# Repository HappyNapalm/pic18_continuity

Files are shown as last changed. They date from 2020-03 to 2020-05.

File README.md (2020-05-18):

# pic18_continuity
Repo for testing continuity

## TODO
* Hammer out the firmware.
* Set timer 3 up as the IO test timer. Make it 8 bits.
* Make footprint for push button.

##License
* Free for non commerical use.
* Remakes and spin offs must give credit to this project.

~Assemble boards to verify designs~

~Verify RJ45~

~Order Alpha Run~

~Get dimensions for DB9 connectors~

~Do battery footprint~

~Learn how to submit multiple boards in one design for vendor~

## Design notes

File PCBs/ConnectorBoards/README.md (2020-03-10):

This dir is to contain the modular boards that the central board can connect to.

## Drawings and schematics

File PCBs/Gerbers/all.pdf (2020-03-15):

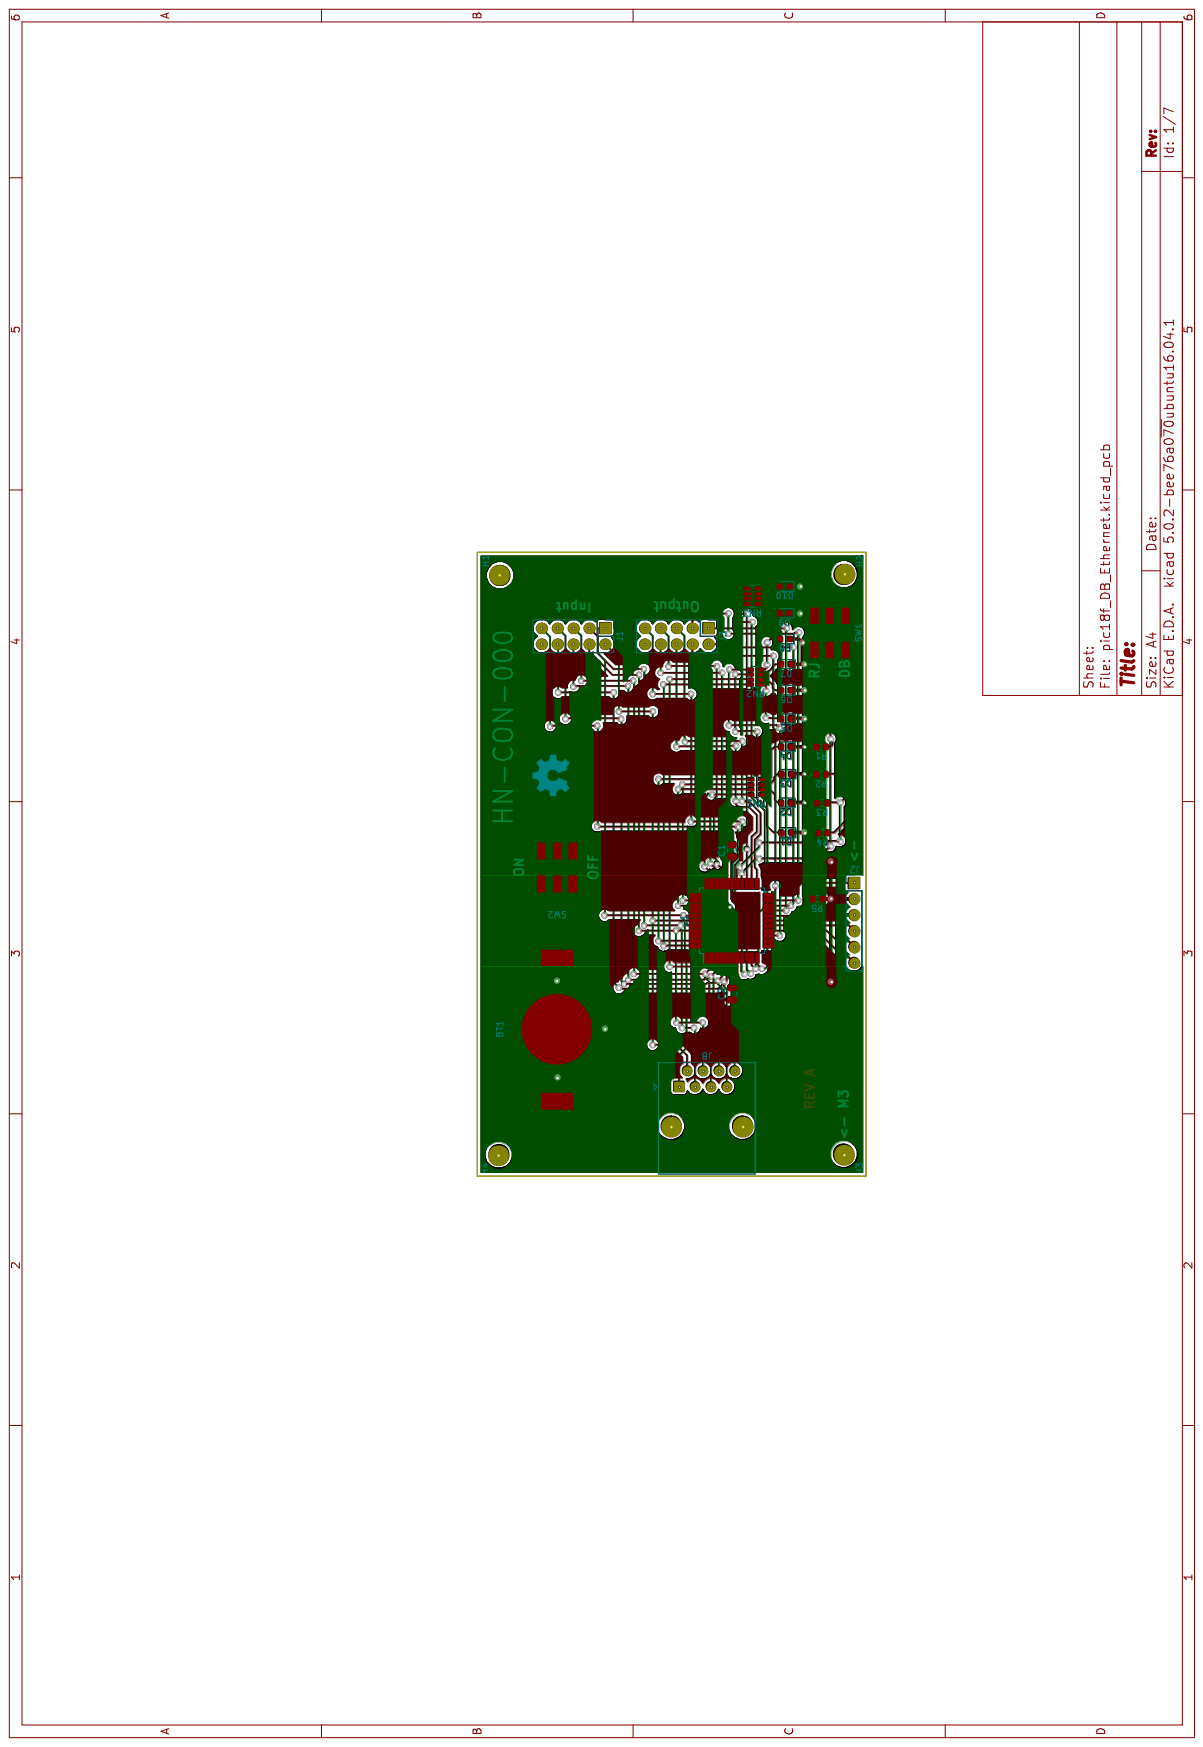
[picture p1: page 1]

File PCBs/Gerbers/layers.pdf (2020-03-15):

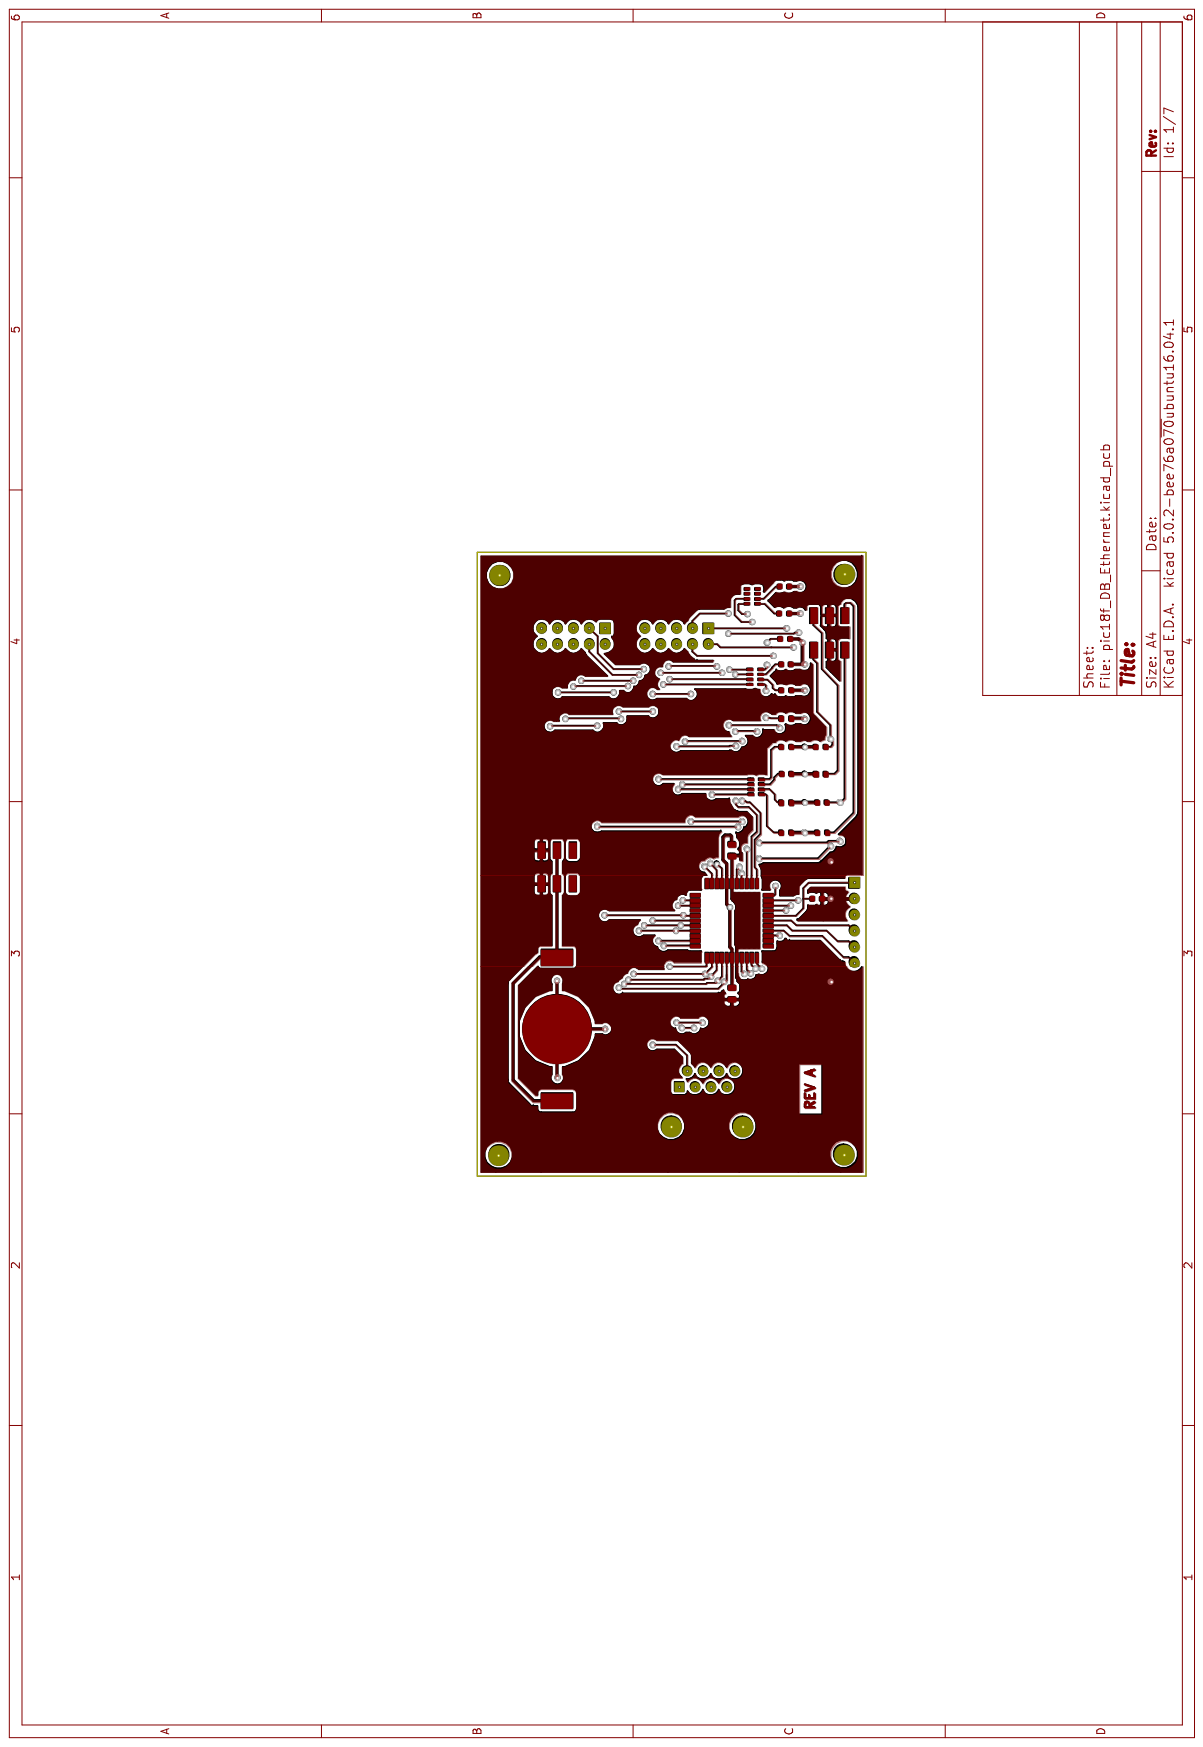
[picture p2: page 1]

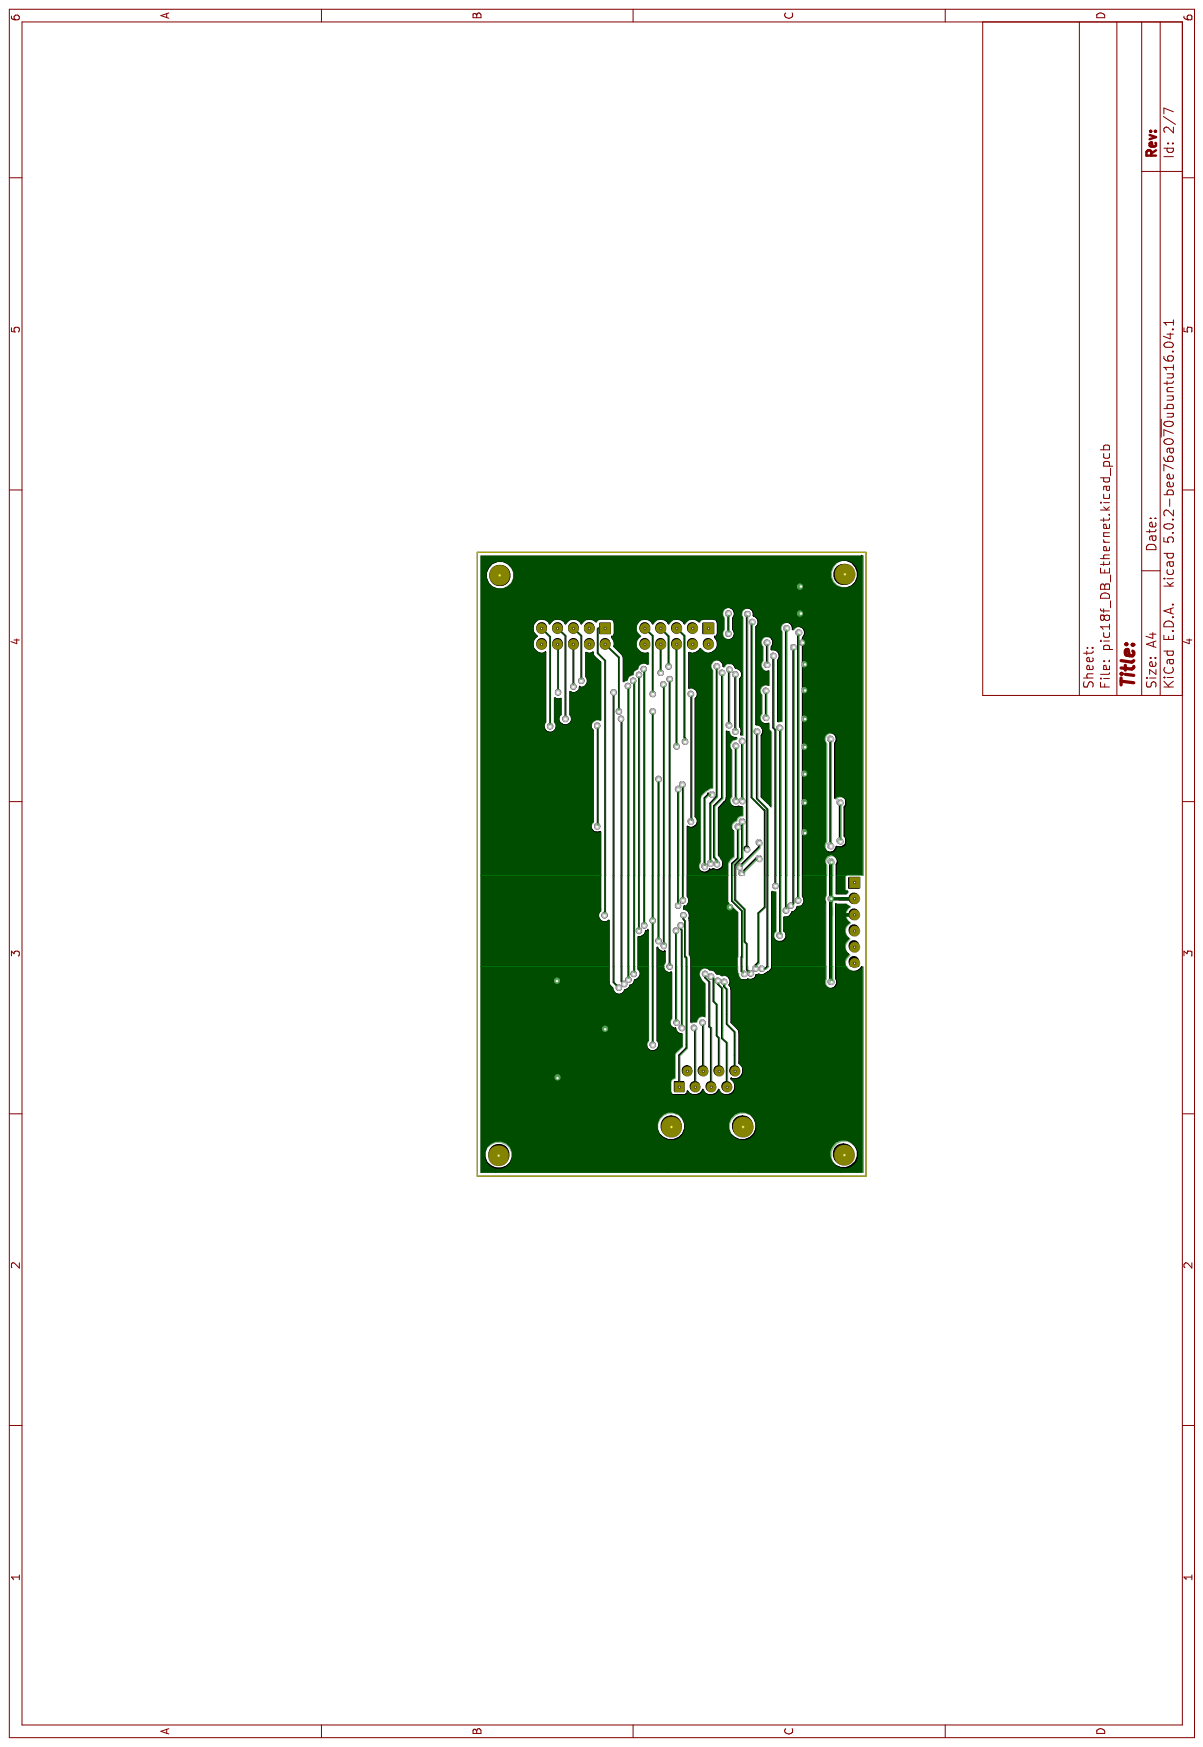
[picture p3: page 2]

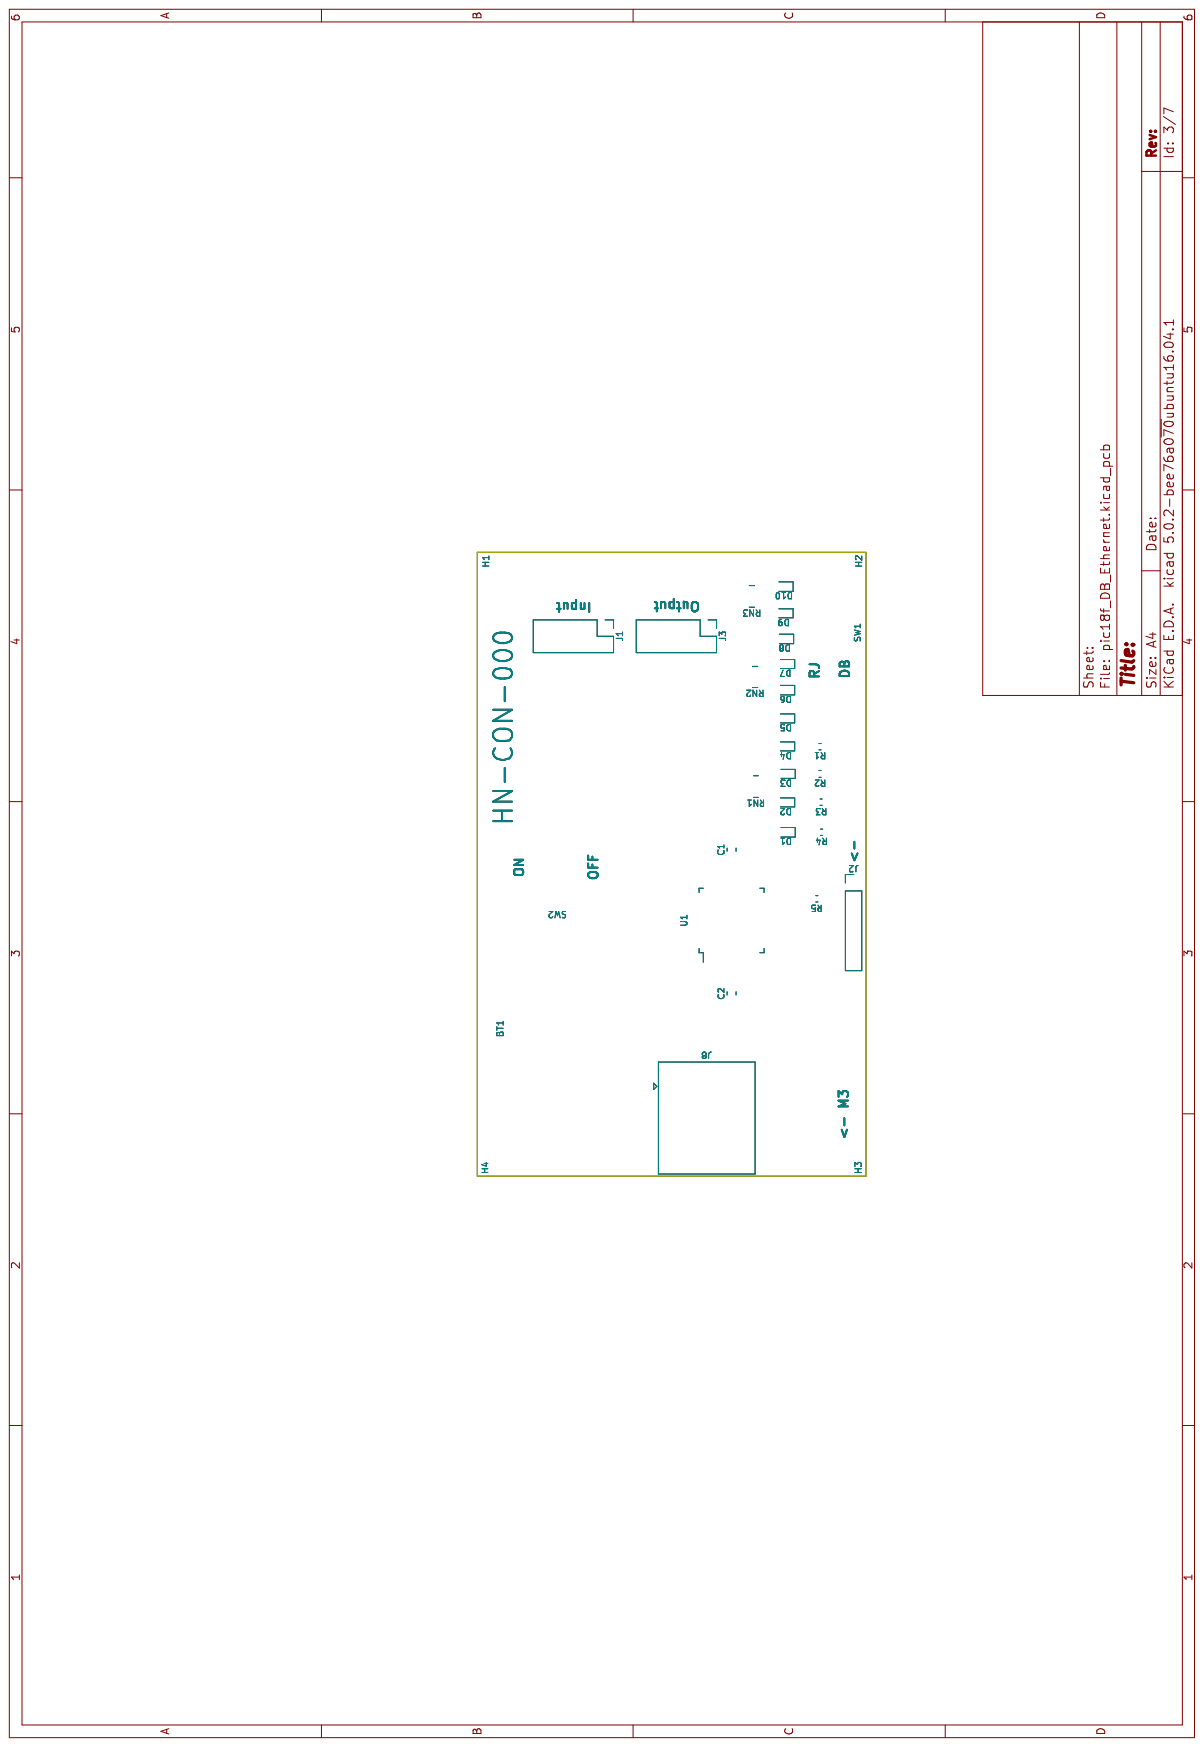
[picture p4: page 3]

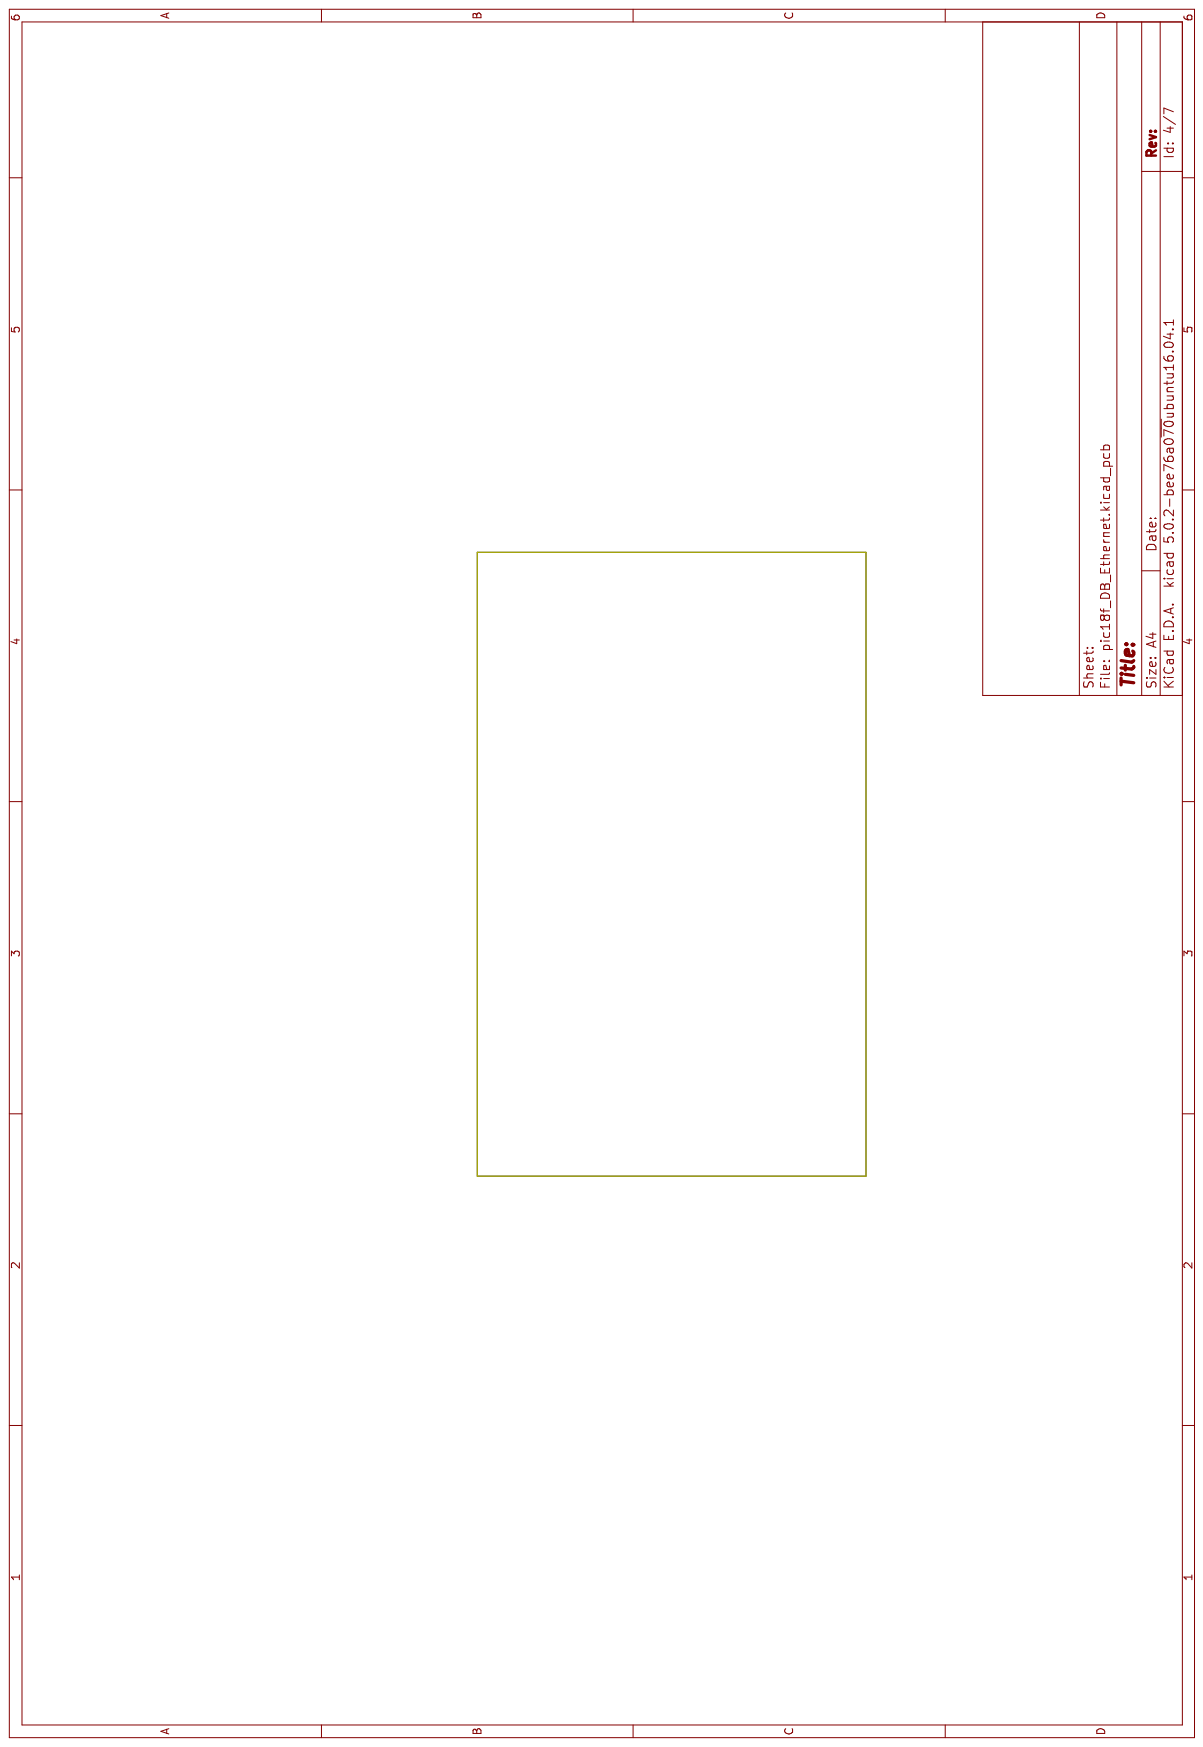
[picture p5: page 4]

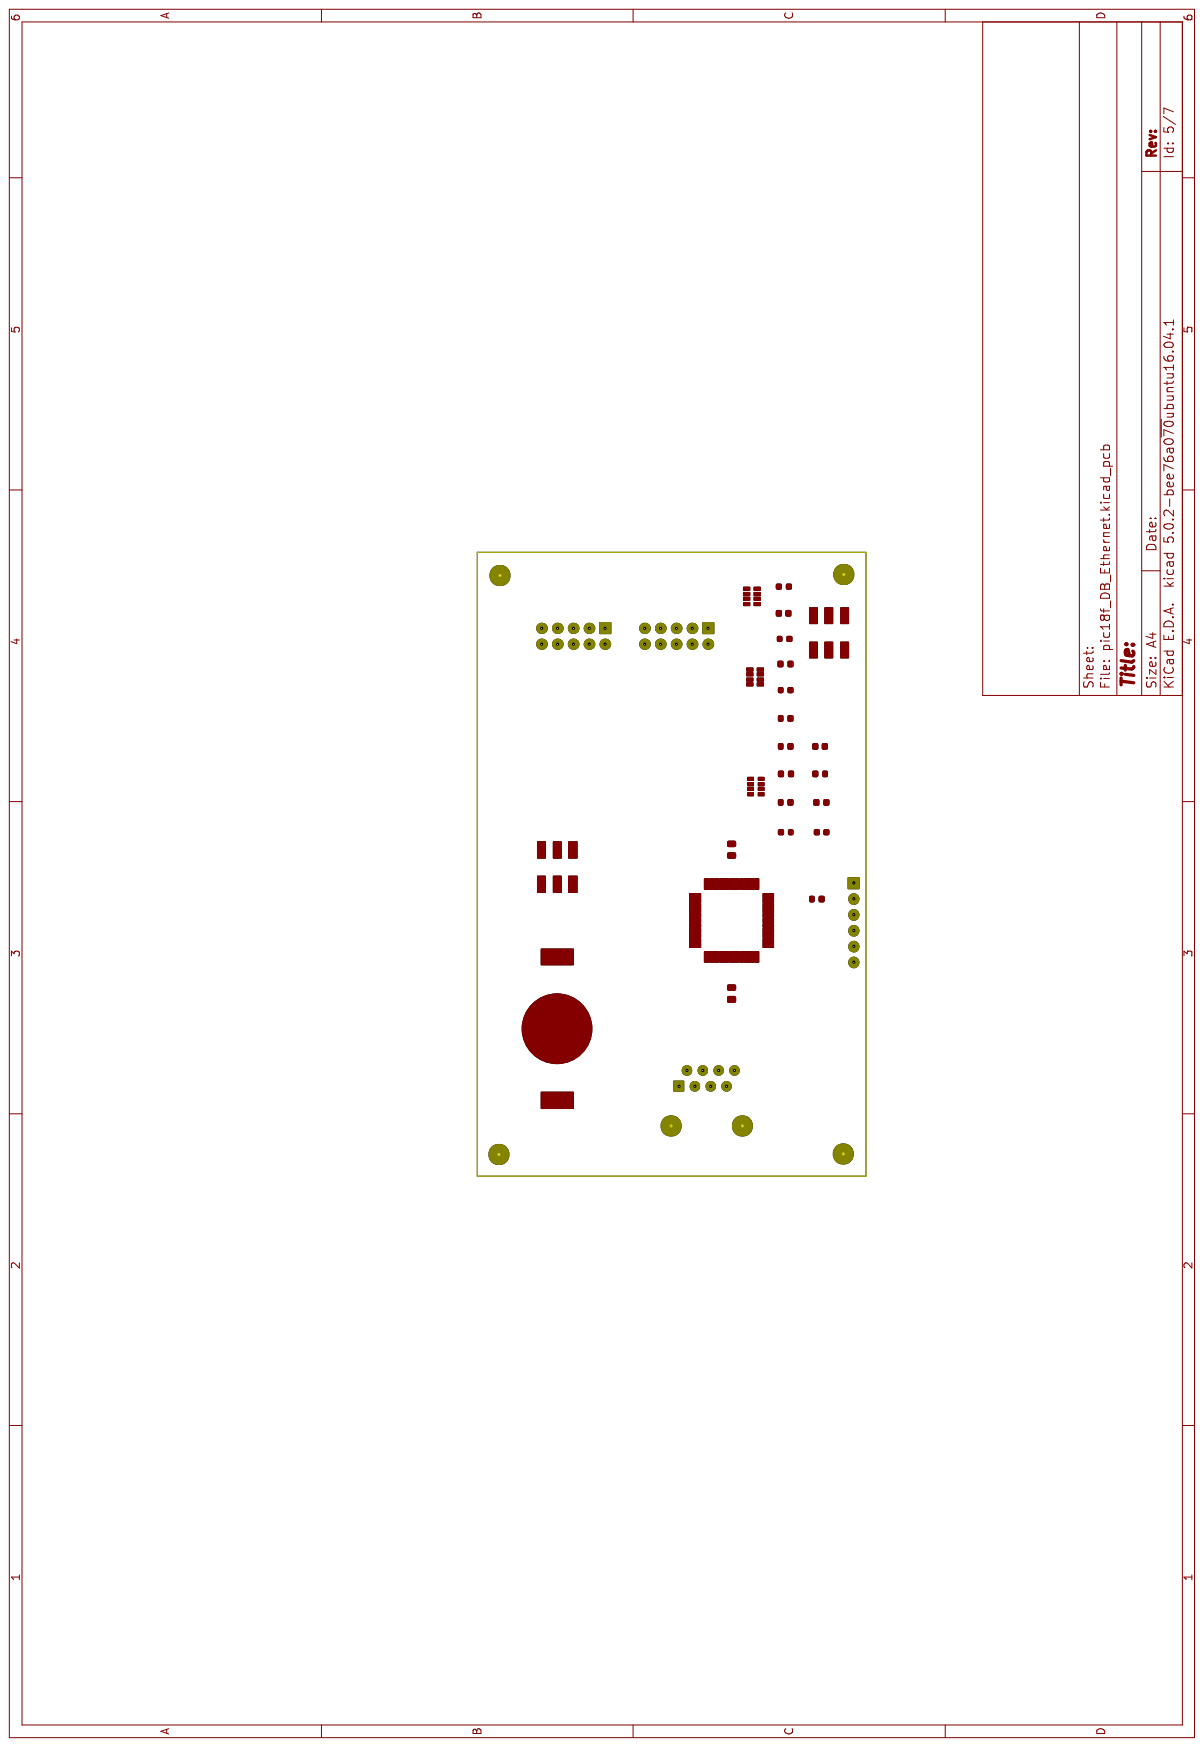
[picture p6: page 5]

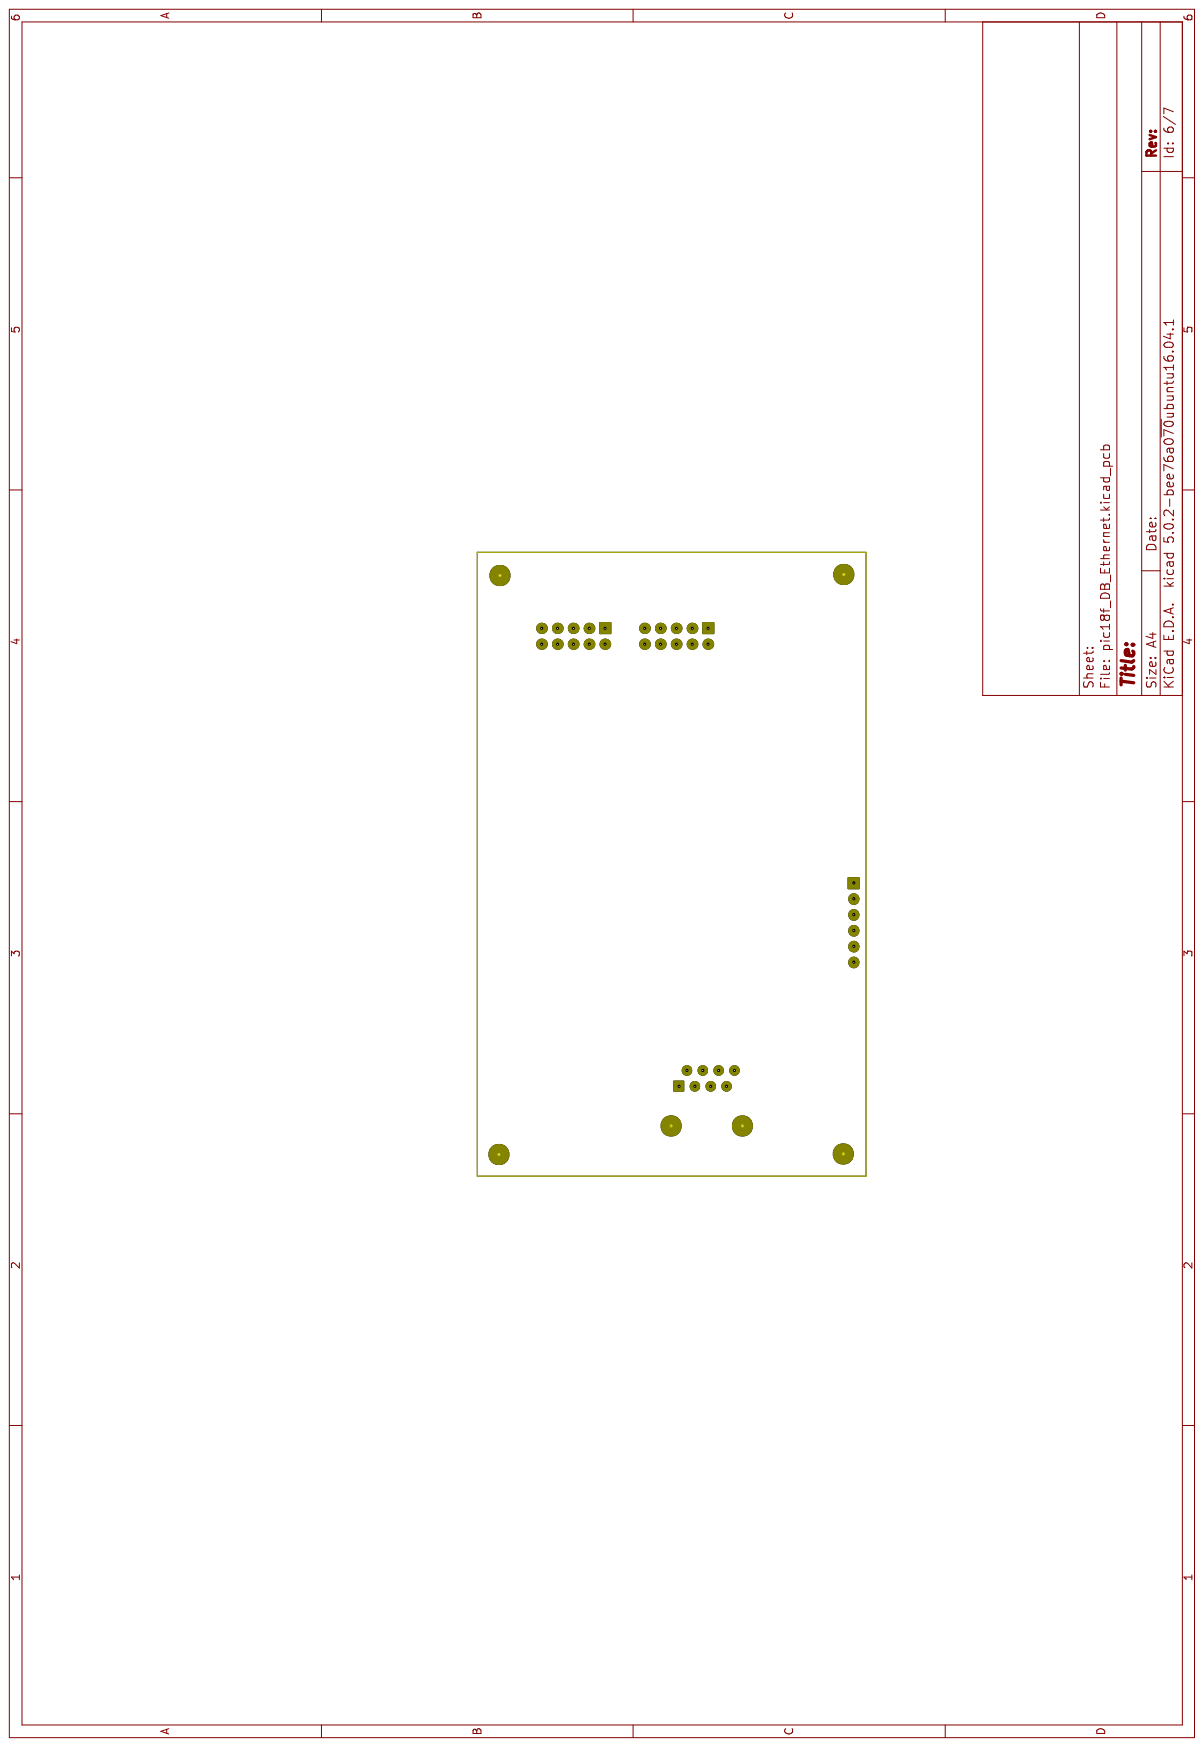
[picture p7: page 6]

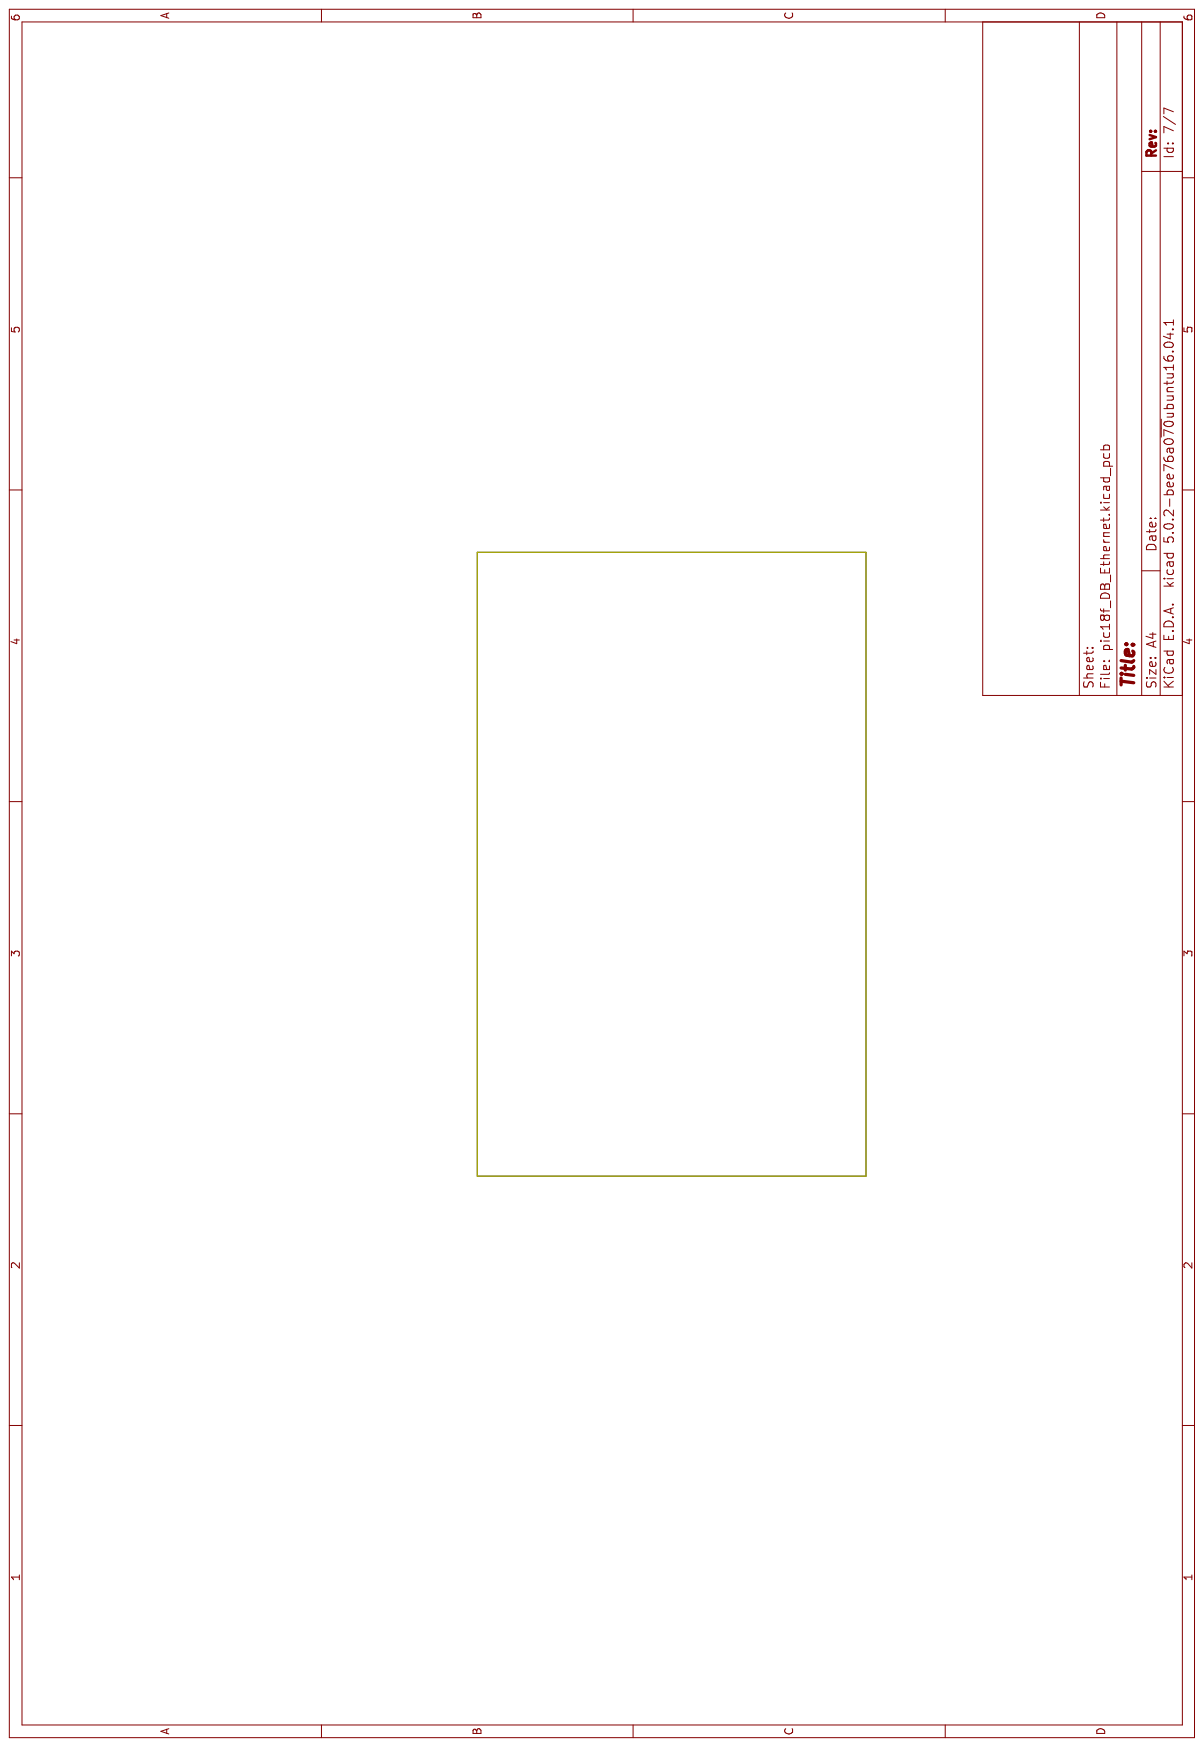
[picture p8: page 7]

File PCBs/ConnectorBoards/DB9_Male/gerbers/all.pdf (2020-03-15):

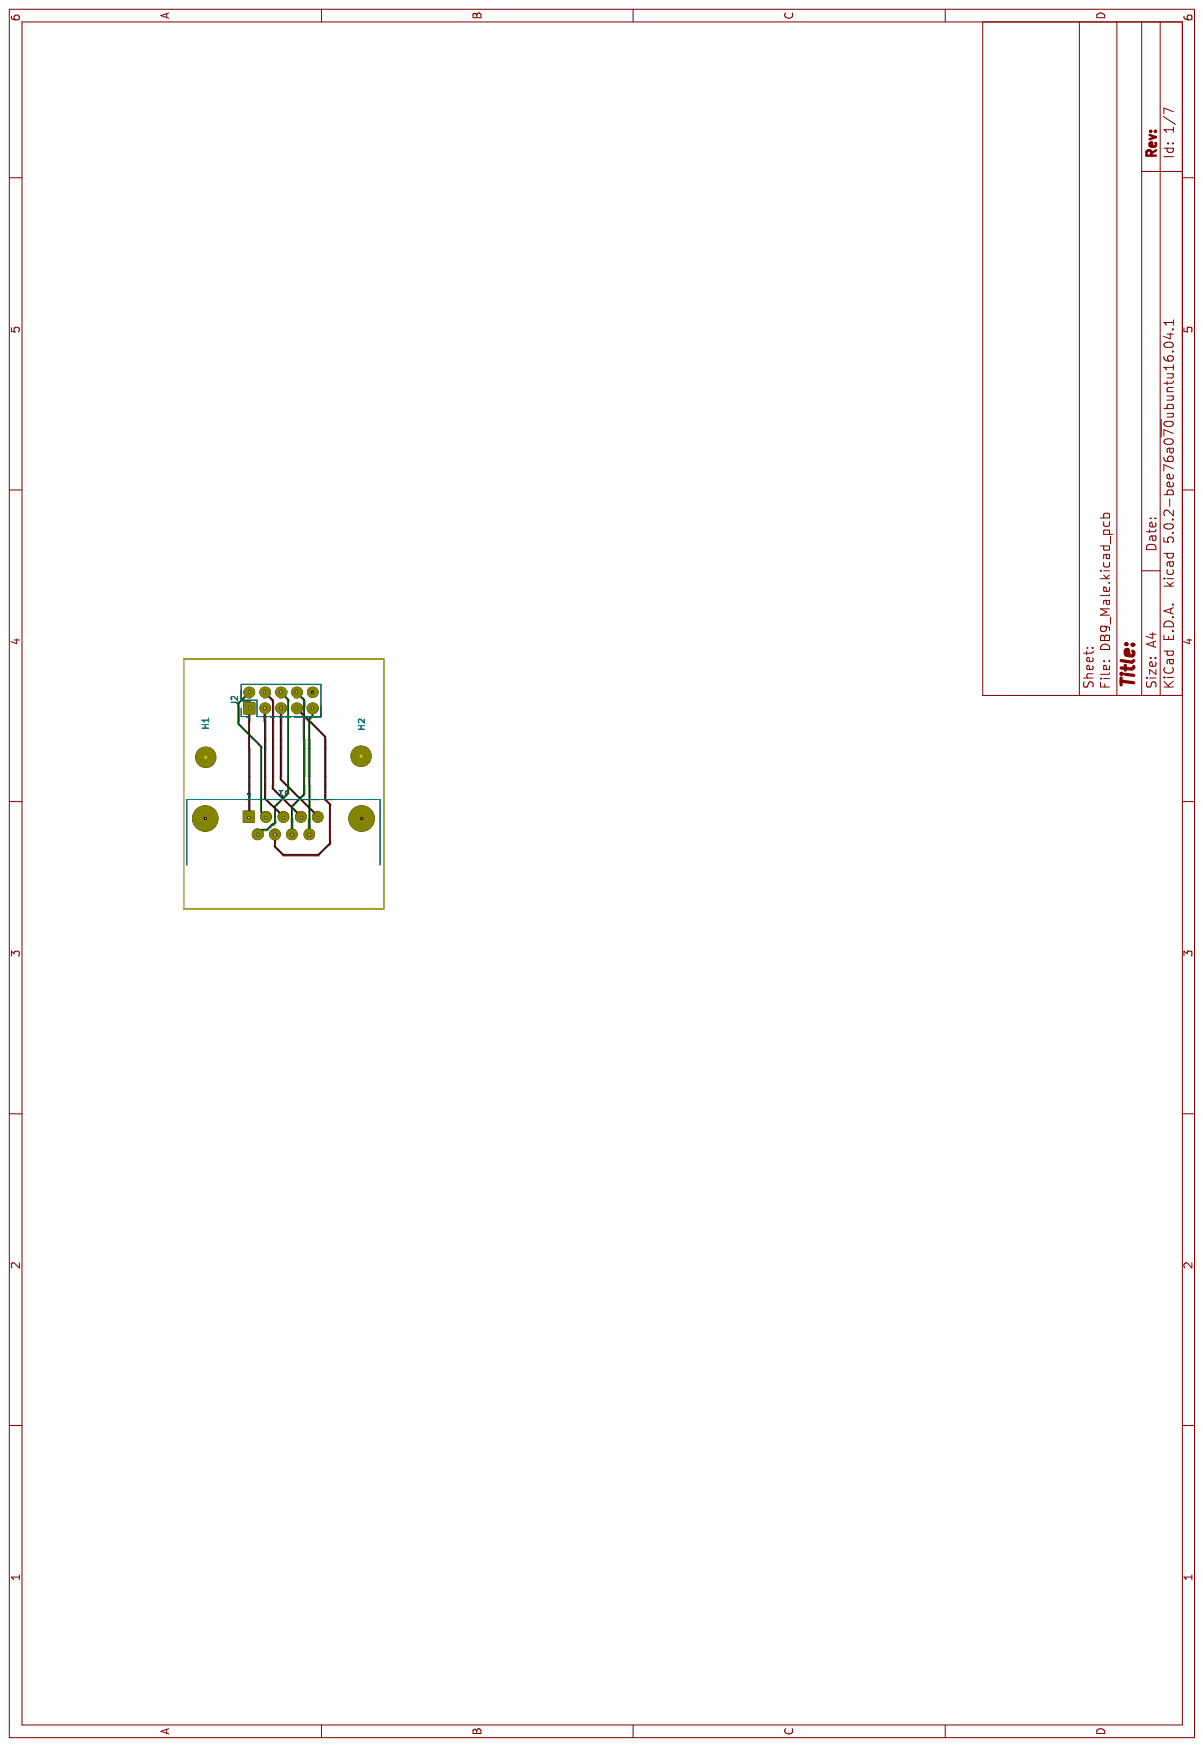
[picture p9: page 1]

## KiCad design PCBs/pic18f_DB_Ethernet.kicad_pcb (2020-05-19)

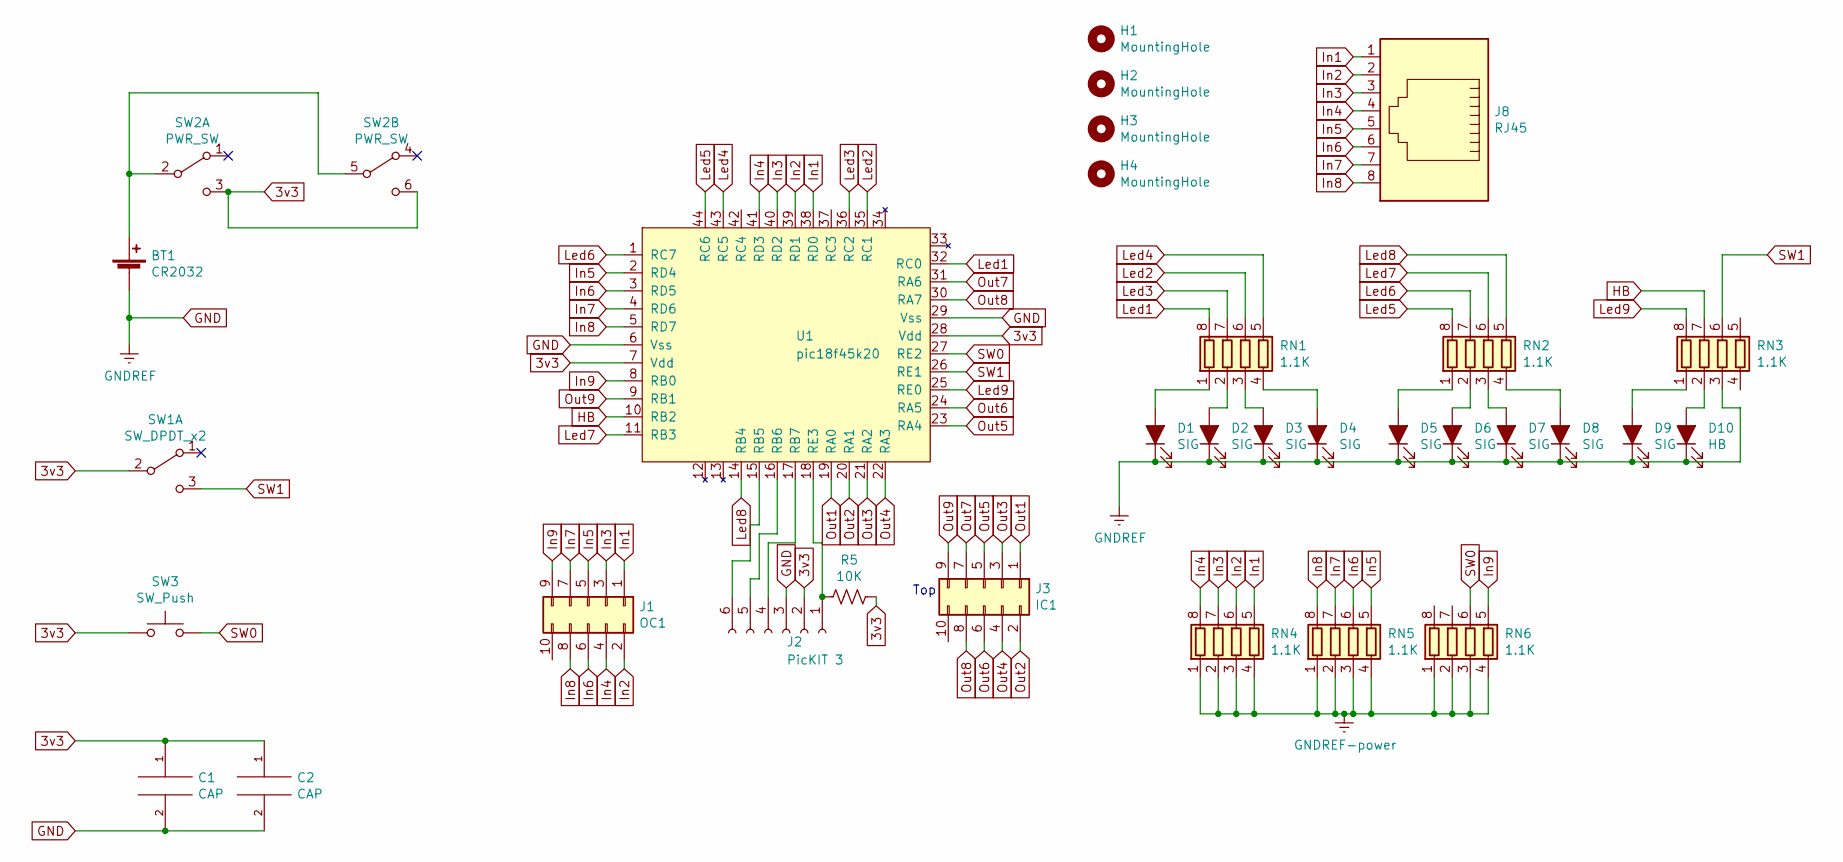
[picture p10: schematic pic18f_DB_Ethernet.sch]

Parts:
BT1: CR2032; BAT-HLD-001
C1, C2: CAP; C_0805_2012Metric
D1, D2, D3, D4, D5, D6, D7, D8, D9: SIG; LED_0603_1608Metric
D10: HB; LED_0603_1608Metric
H1, H2, H3, H4: MountingHole; MountingHole_3.2mm_M3
J1: OC1; PinHeader_2x05_P2.54mm_Vertical
J2: PicKIT 3; PinHeader_1x06_P2.54mm_Vertical
J3: IC1; PinHeader_2x05_P2.54mm_Vertical
J8: RJ45; RJ45_Amphenol_54602-x08_Horizontal
R5: 10K; R_0603_1608Metric
RN1, RN2, RN3, RN4, RN5, RN6: 1.1K; R_Array_Concave_4x0603
SW1: SW_DPDT_x2; JS202011SCQN
SW2: PWR_SW; JS202011SCQN
SW3: SW_Push; SPST_Button_FSM2JRT
U1: pic18f45k20; LQFP-44_10x10mm_P0.8mm

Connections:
3v3: C1.1, C2.1, J2.2, R5.1, SW1.2 (B), SW2.3 (C), SW2.6 (C), SW3.1, U1.7 (Vdd), U1.28 (Vdd)
HB: RN3.7 (R2.2), U1.10 (RB2)
In1: J1.1, J8.1, RN4.5 (R4.2), U1.38 (RD0)
In2: J1.2, J8.2, RN4.6 (R3.2), U1.39 (RD1)
In3: J1.3, J8.3, RN4.7 (R2.2), U1.40 (RD2)
In4: J1.4, J8.4, RN4.8 (R1.2), U1.41 (RD3)
In5: J1.5, J8.5, RN5.5 (R4.2), U1.2 (RD4)
In6: J1.6, J8.6, RN5.6 (R3.2), U1.3 (RD5)
In7: J1.7, J8.7, RN5.7 (R2.2), U1.4 (RD6)
In8: J1.8, J8.8, RN5.8 (R1.2), U1.5 (RD7)
In9: J1.9, RN6.5 (R4.2), U1.8 (RB0)
Led1: RN1.8 (R1.2), U1.32 (RC0)
Led2: RN1.6 (R3.2), U1.35 (RC1)
Led3: RN1.7 (R2.2), U1.36 (RC2)
Led4: RN1.5 (R4.2), U1.43 (RC5)
Led5: RN2.8 (R1.2), U1.44 (RC6)
Led6: RN2.7 (R2.2), U1.1 (RC7)
Led7: RN2.6 (R3.2), U1.11 (RB3)
Led8: RN2.5 (R4.2), U1.14 (RB4)
Led9: RN3.8 (R1.2), U1.25 (RE0)
unnamed: BT1.1 (+), SW2.2 (B), SW2.5 (B)
unnamed: D1.2 (A), RN1.1 (R1.1)
unnamed: D2.2 (A), RN1.2 (R2.1)
unnamed: D3.2 (A), RN1.3 (R3.1)
unnamed: D4.2 (A), RN1.4 (R4.1)
unnamed: D5.2 (A), RN2.1 (R1.1)
unnamed: D6.2 (A), RN2.2 (R2.1)
unnamed: D7.2 (A), RN2.3 (R3.1)
unnamed: D8.2 (A), RN2.4 (R4.1)
unnamed: D9.2 (A), RN3.1 (R1.1)
unnamed: D10.2 (A), RN3.2 (R2.1)
unnamed: J2.1, R5.2, U1.18 (RE3)
unnamed: J2.4, U1.17 (RB7)
unnamed: J2.5, U1.16 (RB6)
unnamed: J2.6, U1.15 (RB5)
Out1: J3.1, U1.19 (RA0)
Out2: J3.2, U1.20 (RA1)
Out3: J3.3, U1.21 (RA2)
Out4: J3.4, U1.22 (RA3)
Out5: J3.5, U1.23 (RA4)
Out6: J3.6, U1.24 (RA5)
Out7: J3.7, U1.31 (RA6)
Out8: J3.8, U1.30 (RA7)
Out9: J3.9, U1.9 (RB1)
SW0: RN6.6 (R3.2), SW3.2, U1.27 (RE2)
SW1: RN3.6 (R3.2), SW1.3 (C), U1.26 (RE1)

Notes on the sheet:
Top

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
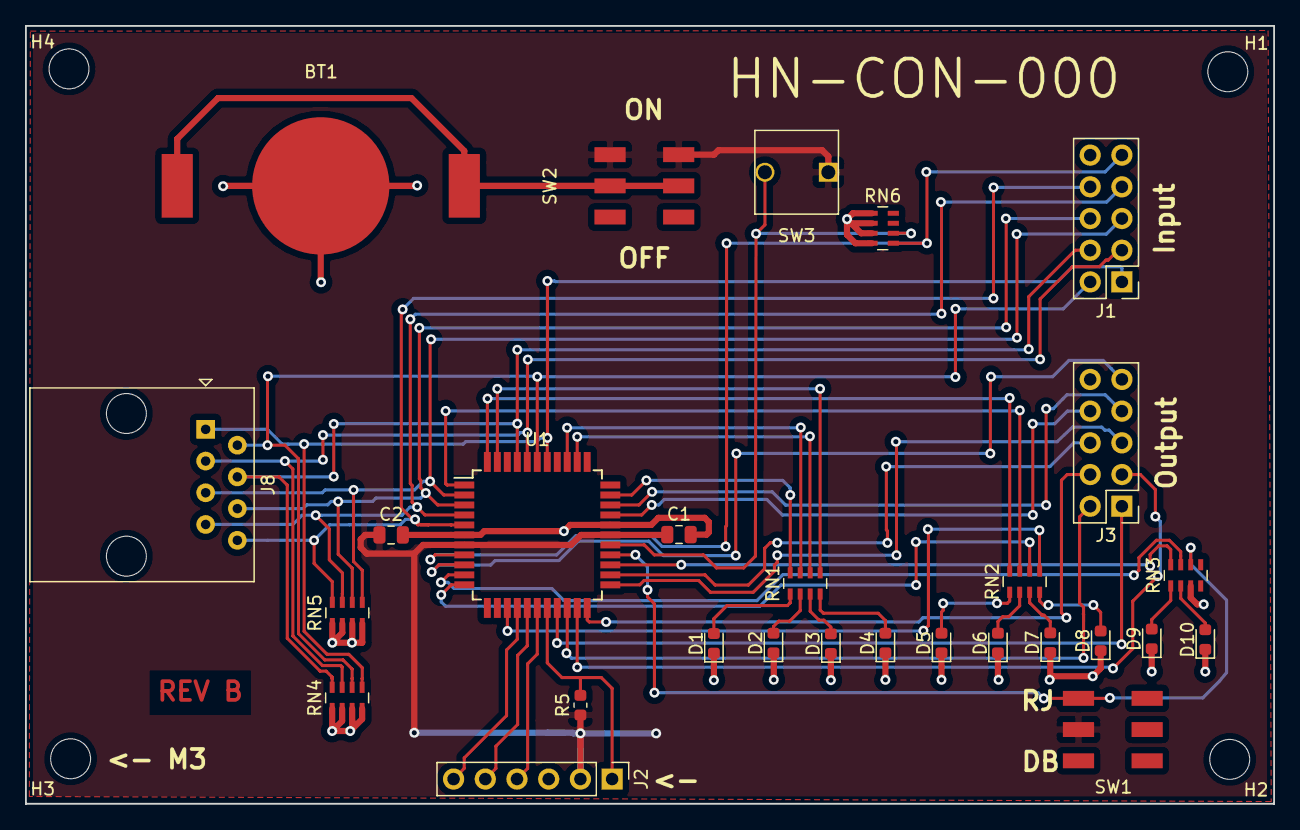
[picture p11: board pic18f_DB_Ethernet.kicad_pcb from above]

Board: 2 copper layers, 100.0 x 62.3 mm, 32 parts (0 on the bottom side), 47 nets.

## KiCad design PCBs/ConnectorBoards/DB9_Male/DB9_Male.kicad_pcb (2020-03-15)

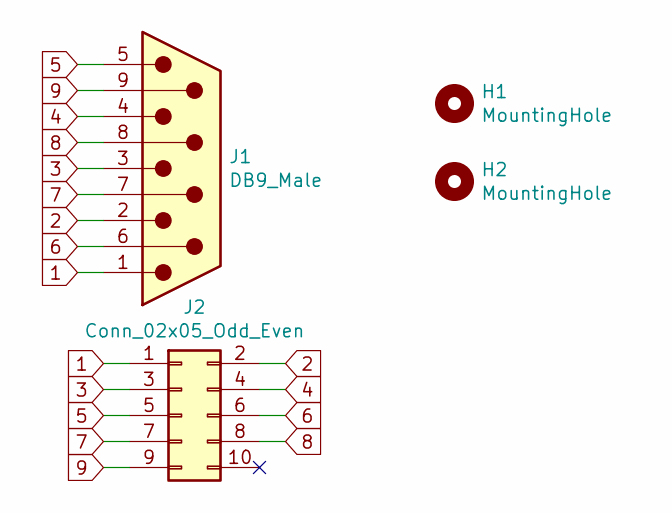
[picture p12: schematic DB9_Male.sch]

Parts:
H1, H2: MountingHole; MountingHole_3.2mm_M3
J1: DB9_Male; DSUB-9_Male_Horizontal_P2.77x2.84mm_EdgePinOffset4.94mm_Hou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
J2: Conn_02x05_Odd_Even; PinHeader_2x05_P2.54mm_Vertical

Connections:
1: J1.1, J2.1
2: J1.2, J2.2
3: J1.3, J2.3
4: J1.4, J2.4
5: J1.5, J2.5
6: J1.6, J2.6
7: J1.7, J2.7
8: J1.8, J2.8
9: J1.9, J2.9

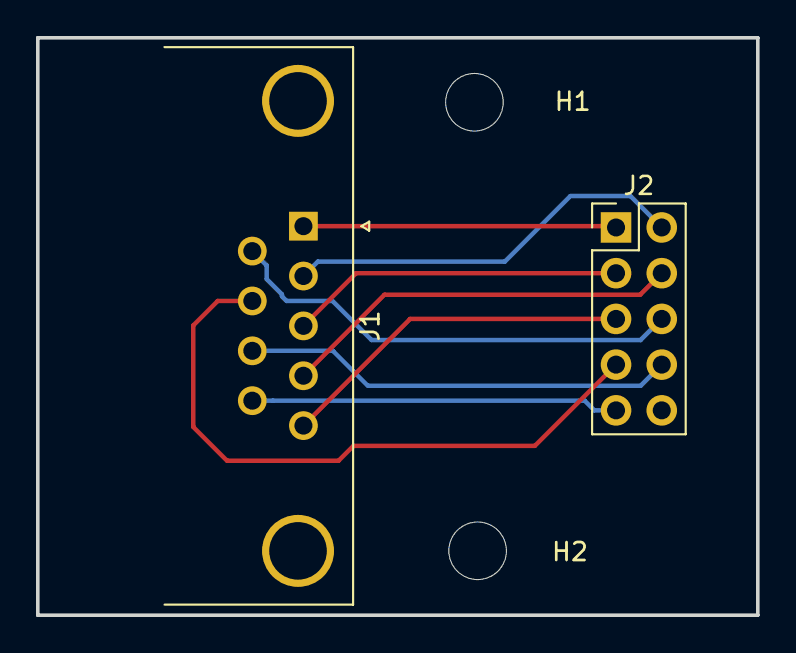
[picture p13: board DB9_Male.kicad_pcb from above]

Board: 2 copper layers, 40.0 x 32.1 mm, 4 parts (0 on the bottom side), 9 nets.

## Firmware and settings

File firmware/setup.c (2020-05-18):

#include <stdio.h>
//#include <stdlib.h>
#include <xc.h>
#include <htc.h>
#include "setup.h"
#include "leds.h"

//@About set GPIO table item to boolean
void set_IO (struct gstGPIO *IO, unsigned char item,unsigned char bValue)
{
    volatile unsigned char *ucLocal;
    ucLocal = IO[item].port;
    if (bValue)
    {
        *ucLocal |= (1 << IO[item].pin);
    }
    else
    {
        *ucLocal &= ~(1 << IO[item].pin);
    }
}

//@About get the state of an item from a GPIO table
unsigned char get_IO (struct gstGPIO *IO, unsigned char item)
{
    return (unsigned char)((*IO[item].port >> IO[item].pin) & 0x01);
}

struct gstGPIO astInputs[] = {
    {&PORTD, 0},
    {&PORTD, 1},
    {&PORTD, 2},
    {&PORTD, 3},
    {&PORTD, 4},
    {&PORTD, 5},
    {&PORTD, 6},
    {&PORTD, 7},
    {&PORTB, 0},
};

struct gstGPIO astOutputs[] = {
    {&LATA, 0},
    {&LATA, 1},
    {&LATA, 2},
    {&LATA, 3},
    {&LATA, 4},
    {&LATA, 5},
    {&LATA, 6},
    {&LATA, 7},
    {&LATB, 1},
};

void IO_setup (void)
{
  TRISA = 0x00;           //Outputs
  TRISC = 0x00;           //LEDS
  TRISBbits.RB0 = 1;      //In9
  TRISBbits.RB1 = 0;      //Out9
  TRISBbits.RB2 = 0;      //HB
  TRISBbits.RB3 = 0;      //LED7
  TRISBbits.RB4 = 0;      //LED8
  TRISD = 0xFF;           //Inputs
  TRISEbits.RE0 = 0;      //LED9
  TRISEbits.RE1 = 1;      //Switch 1A
  TRISEbits.RE2 = 1;      //Switch 1B
}


void Timer_and_Interrupt_setup (void)
{
    //Let this timer run as a free running timer
    
    //16 bits. 1:64 prescaler. Internal. 1 tick is 8us
    T0CON = 0b10010101;
    //INTCONbits.TMR0IE = 1;
    
    //8Mhz timer. Internal
    OSCCON = 0b01100111;
    
    
    T3CON = 0b00000101;
}

void clr_Timer (void)
{
    TMR0H = 0;
    TMR0L = 0;
}

void clr_Timer3 (void)
{
    TMR3H = 0;
    TMR3L = 0;
}

void __interrupt() ISR()
{
    if(TMR0IF)
    {
        TMR0IF = 0;
        clr_Timer();
        HB = !HB;
        gbTick++;
    }
    if(TMR3IF)
    {
        TMR3IF = 0;
        clr_Timer3();
        guc_3_Tick++;
        gucTestBit++;
    }
}

inline volatile unsigned short get_Time(void)
{
    return ((unsigned short)(TMR0H << 8) | TMR0L);
}

//@About: Checks with the free running timer
unsigned char bTimeUp(
                        unsigned short StartTime,
                        /*unsigned char StartOverFlowCount,*/
                        unsigned short Period
                     )
{
    unsigned char b = 0;
    unsigned short CurrentTime = get_Time();
    
    if (CurrentTime < StartTime)
    {
//        if(StartOverFlowCount > gbTick)
//        {
            if(((0xFFFF - StartTime) + CurrentTime) >= Period)
                {
                    b = 1;
                }
//        }
    }
    else if (CurrentTime - StartTime >= Period)
    {
        b = 1;
    }
    return b;
}

void setup(void)
{
    INTCONbits.GIE = 0;
    IO_setup();
    //clr_Timer();
    HB = 0;
    Timer_and_Interrupt_setup();
    INTCONbits.GIE = 1;
    INTCONbits.PEIE = 1;
    INTCONbits.TMR0IE = 1;
    T0CONbits.TMR0ON = 1;
    T3CONbits.TMR3ON = 0;
    all_LEDs();
    
    
}

#define HB_PERIOD 10000
void heartbeat(void)
{
    static unsigned char nbFirst;
    static unsigned short uwStartTime;
    static unsigned char ucOverFlow;
    //unsigned short uwCurrentTime = get_Time();
    if(!nbFirst)
    {
        uwStartTime = get_Time();
        ucOverFlow = gbTick;
        nbFirst = 1;
    }
    else
    {
        if(bTimeUp(uwStartTime,/*ucOverFlow,*/HB_PERIOD))
        {
            HB = !HB;
        }
    }
}

void compare_IO(unsigned char TargetBit)
{
    unsigned char bOutput = get_IO(astOutputs,TargetBit);
    unsigned char bInput  = get_IO(astInputs ,TargetBit);
    set_IO(astLEDs,TargetBit,(bOutput == bInput==1));
    
}

void testing(unsigned char TargetBit)
{
    static unsigned char b;
    static unsigned char ucLocalTicks;
    static unsigned char nbFirst;
    if(!nbFirst)
    {
        b = 1;
        nbFirst = 1;
        ucLocalTicks = guc_3_Tick;
        T3CONbits.TMR3ON = 1;   //Start the timer
    }
    if(ucLocalTicks != guc_3_Tick)
    {
        T3CONbits.TMR3ON = 0;
        b = 0;
        nbFirst = 0;
    }
    set_IO(astOutputs,TargetBit,b);
    compare_IO(TargetBit);
}

//# Potential EEPROM code below #//

// unsigned char read_eeprom(unsigned char ucAddress)
// {
//   unsigned char Data;
//   EEADR = ucAddress;       // Write The Address From Which We Wonna Get Data
//   EECON1bits.EEPGD = 0;  // Cleared To Point To EEPROM Not The Program Memory
//   EECON1bits.RD = 1;     // Start The Read Operation
//   Data = EEDATA;         // Read The Data
//   return (Data);

// }

// void write_eeprom(unsigned char ucAddress, unsigned char ucData)
// {
//   while(EECON1bits.WR);  // Waits Until Last Attempt To Write Is Finished
//   EEADR = ucAddress;       // Writes The Addres To Which We'll Wite Our Data
//   EEDATA = ucData;         // Write The Data To Be Saved
//   EECON1bits.EEPGD = 0;  // Cleared To Point To EEPROM Not The Program Memory
//   EECON1bits.WREN = 1;   // Enable The Operation !
//   INTCONbits.GIE = 0;    // Disable All Interrupts Untill Writting Data Is Done
//   EECON2 = 0x55;         // Part Of Writing Mechanism..
//   EECON2 = 0xAA;         // Part Of Writing Mechanism..
//   EECON1bits.WR = 1;     // Part Of Writing Mechanism..
//   INTCONbits.GIE = 1;    // Re-Enable Interrupts
//   EECON1bits.WREN = 0;   // Disable The Operation
//   EECON1bits.WR = 0;     // Ready For Next Writting Operation             
// }

// void reset_eeprom(void)
// {
//     unsigned char byte_count;
//     for(byte_count = 0; byte_count < 100; byte_count++)
//     {
//         write_eeprom(byte_count,0xff);
//     }
// }

// void HEX_2_LED(unsigned char EEPROM_MEM_ADDRESS)
// {
//     unsigned char LED_1;
//     unsigned char LED_2;
//     LED_1 = EEPROM_MEM_ADDRESS & 0x0F;
//     LED_2 = (EEPROM_MEM_ADDRESS & 0xF0 >> 4);
//     LED_Output_Single(LED_1,1);
//     LED_Output_Single(LED_2,1);
// }

// //On power up make it so you cycle through the EEPROM from 0-95 (six passes)
// //Read until you find one that mets the following criteria:
// //  (1) Not 0xFF
// //  (2) Highest value found
// //  (3) Then increment the value
// //  (4) Read the value and modulate by 16 to get the animation timer.
// //  (5) Assume that 0xFF at address 0 means we have restarted
// //  (6) If at address 95, then we can reset.


// void start_up(void)
// {
//     unsigned char ucDataOut = 0;
//     unsigned char ucValid = 0;
    
//     ucDataOut = read_eeprom(0x0A);
//     if(ucDataOut > 7)
//     {
//         ucDataOut = 0;
//     }
//     gucAnimationState = ucDataOut;
//     write_eeprom(0x0A,(ucDataOut+1));
// }

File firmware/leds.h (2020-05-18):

/* 
 * File:   leds.h
 * Author: church
 *
 * Created on April 5, 2020, 5:24 PM
 */

#ifndef LEDS_H
#define	LEDS_H

#ifdef	__cplusplus
extern "C" {
#endif




#ifdef	__cplusplus
}
#endif

//Macros
#define LED1  LATCbits.LC0
#define LED2  LATCbits.LC2
#define LED3  LATCbits.LC1
#define LED4  LATCbits.LC5
#define LED5  LATCbits.LC6
#define LED6  LATCbits.LC7
#define LED7  LATBbits.LB3
#define LED8  LATBbits.LB4
#define LED9  LATEbits.LE0


//Global Vars
struct gstGPIO astLEDs[MAX_IO] = {
    { &LATC, 0 },  /*LED1*/
    { &LATC, 2 },  /*LED2*/
    { &LATC, 1 },  /*LED3*/
    { &LATC, 5 },  /*LED4*/
    { &LATC, 6 },  /*LED5*/
    { &LATC, 7 },  /*LED6*/
    { &LATB, 3 },  /*LED7*/
    { &LATB, 4 },  /*LED8*/
    { &LATE, 0 },  /*LED9*/
};
//extern const struct gstLEDs;

//Functions
extern void clr_LEDs (void);
extern void all_LEDs (void);
extern unsigned short get_LEDs (void);
extern void walk_LEDs (void);

#endif	/* SETUP_H */

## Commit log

2020-02-23 Initial KiCAD files
    [pic18f_DB_Ethernet.kicad_pcb, pic18f_DB_Ethernet.sch]
2020-02-23 TODO: Programming header. TODO: incorporate cabling design for connector modules.
    [pic18f_DB_Ethernet.sch]
2020-02-25 some basic connections laid down. TODO: double check I2C pins. Programming pins. And inputs.
    [pic18f_DB_Ethernet.sch]
2020-02-27 Finished basic schematic
    [pic18f_DB_Ethernet.sch]
2020-02-27 generated a basic net list
    [pic18f_DB_Ethernet.sch]
2020-02-29 Basic datasheets for the DB9 connectors
2020-02-29 Basic routing of known components complete. TODO: Outline, mouse bites, missing parts
    [pic18f_DB_Ethernet.kicad_pcb]
2020-03-07 Added dpdt switch from stock. added battery clip. Reconsidering mouser bites. TODO: Orthagonal repo of parts rendered in KiCAD.
    [pic18f_DB_Ethernet.kicad_pcb, pic18f_DB_Ethernet.sch]
2020-03-10 Finished Rev A layout. Some research revealed that JLCPCB does not support what I want. I might just send the break out into a different pcb.
    [pic18f_DB_Ethernet.kicad_pcb, pic18f_DB_Ethernet.sch]
2020-03-10 Restructed project
    [DB9_Female.kicad_pcb, DB9_Female.sch, DB9_Male.kicad_pcb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]
2020-03-13 Minor rerouting to address power trace width. Added OSHW logo. Updated todo list
    [pic18f_DB_Ethernet.kicad_pcb]
2020-03-15 changed RJ45 jack to unsheilded. Printed main board gerbers and gerber pdfs
    [pic18f_DB_Ethernet-B.Cu.gbr, pic18f_DB_Ethernet-B.Mask.gbr, pic18f_DB_Ethernet-B.Paste.gbr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]
2020-03-15 generated the male pcbs
    [DB9_Male-B.Cu.gbr, DB9_Male-B.Mask.gbr, DB9_Male-B.Paste.gbr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]
2020-03-31 Noodling through basic designs. TODO assemble and document boards
2020-04-17 Saving progress. Reused Flash LEDS as a jog through all the LEDs. TODO: Make an LED breakout board for testing IO. Note: I am eating through battery much faster than expected. Consider introducing po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
2020-04-17 Hammered the interrupts. Rough FRT working. Time to refine and add some defensive programming.
2020-04-18 Debugging the FRT. Bugs were found.
    [main.c, setup.c]
2020-04-18 Making a branch of the software without the free running timer.
2020-04-23 Working on the IO routines. (Probably missing pull down resistors. Will need to make a test board to verify hardware.) TODO configure processor to make debugging easier.
    [leds.h, main.c, setup.c]
2020-04-23 Issue discovered with IO testing. Further debug required.
    [main.c, setup.c]
2020-05-18 addressing hardware problems on PCB design. Pull downs missing and while a breakout works for prototyping code, it is time to commit the changes in FR4.
    [pic18f_DB_Ethernet.kicad_pcb]
2020-05-18 Updated todo list in the readme. Need to make button footprint.
2020-05-19 Finished REV B design.
    [pic18f_DB_Ethernet.kicad_pcb, pic18f_DB_Ethernet.sch]
